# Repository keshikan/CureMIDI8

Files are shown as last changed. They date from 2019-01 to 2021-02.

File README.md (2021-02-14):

# USB-MIDI Interface (8IN/8OUT) for STM32 "CureMIDI8"

## Overview (概要)

This repository shows STM32F7 (ARM Cortex-M7) based  8IN/8OUT USB-MIDI Interface.
It is USB MIDI class-compliant, so you can add MIDI port without drivers(Windows, iOS, Android, etc...)

The USB-MIDI Class Driver is based on [mimuz-tuch](https://github.com/mimuz/mimuz-tuch) project (c) [D.F.Mac. @TripArts Music](https://github.com/tadfmac).

STM32F7を使用した、USB-MIDIインターフェースです。INを8系統、OUTを8系統実装しています。USB MIDI Classに対応するシステム(Windows, iOS, Android, etc.)に対し、ドライバレスでMIDI入出力ポートを追加できます。

USB MIDI Classドライバは、[D.F.Mac. @TripArts Music](https://github.com/tadfmac)氏作成の[ドライバ](https://github.com/mimuz/mimuz-tuch/tree/master/STM32)を元に、I/F部(usbd_midi_if.c/h)の改造を行っています。

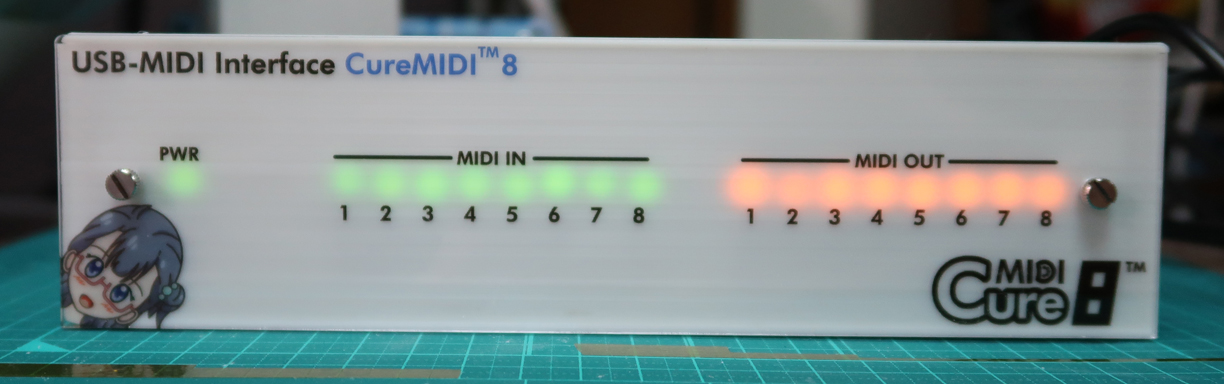
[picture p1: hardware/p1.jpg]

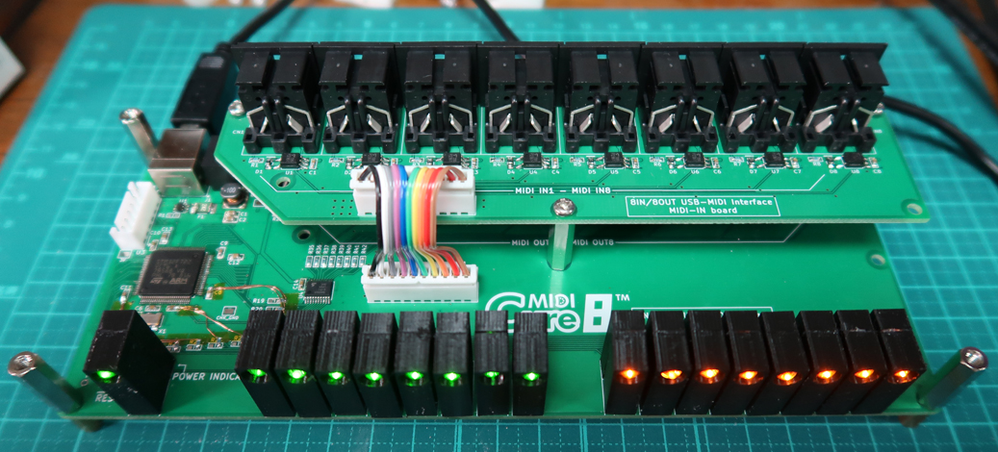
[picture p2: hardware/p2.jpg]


## Specifications (特徴)

* High-Speed MCU (STM32F722VCT)
* USB MIDI class-compliant
* MIDI port: 8IN/8OUT
* MIDI buffer size: 2kB * (8IN+8OUT) = 32kB

## Building Information (ビルド方法)

### Making hardware

See [Schematic](./hardware/schematic.pdf), [KiCad Source](./hardware/kicad_source).
CureMIDI8 consist of a mainboard and a MIDI-IN board.

回路図は[こちら](./hardware/schematic.pdf).
CureMIDI8は、メイン基板(Mainboard)と、拡張基板(MIDI-IN board)に分かれています。

### Building software

Install [STM32CubeIDE](https://www.st.com/ja/development-tools/stm32cubeide.html), import [Project files](./software/CubeIDE_project/). If you have successfully imported, you can build the project without error and the binary file will be created in /CubeIDE_project/Debug/.

[STM32CubeIDE](https://www.st.com/ja/development-tools/stm32cubeide.html)をインストールし、[プロジェクトファイル](./software/CubeIDE_project/)をインポートして下さい。インポートに成功していれば、STM32CubeIDE上でプロジェクトをビルドするだけで、/SW4STM32_project/Debug/フォルダにバイナリファイルが生成されるはずです。

## How to Porting (ポーティング方法)

### CubeIDE Project (recommended)

Refer to [here](software/README.md). (written in Japanese)

[こちら](software/README.md)を参照して下さい。

### SW4STM32 Project

(Older Information)
Load CureMIDI8.ioc on [STM32CubeMX (Ver.5.0.1)](https://www.st.com/ja/development-tools/stm32cubemx.html), change the pin assignment, and generate code.
After code generation, copy usb device driver as described below. You can use ./click_after_code_generation.bat (in Windows).

(以下は古い情報です)
CureMIDI8.iocを[STM32CubeMX (Ver.5.0.1)](https://www.st.com/ja/development-tools/stm32cubemx.html)で読みこみ、ポートを適宜修正し、コード生成をして下さい。コードを生成後、./template下のUSBドライバを、下記の通り上書きして下さい。上書きは、./click_after_code_generation.batを実行してもOKです。

* ./template/\*.c => ./Src/\*.c
* ./template/\*.h => ./Inc/\*.h

## File Location (ファイルの場所)

* [Binary file for STM32F722](./software/bin/)
* [STM32CubeIDE + STM32CubeMX(6.1.1) Project file](./software/CubeIDE_Project/)
* [SW4STM32 + STM32CubeMX(5.0.1) Project file](./software/SW4STM32_project/)
* [Schematic](./hardware/schematic.pdf)

## NOTICE (注意)

### VID/PID

Vendor ID(VID) and Product ID(PID) in <usbd_desc.c> should be unique pair for each USB devices.
Default VID 0x1209 and PID 0x0001 is experimental IDs from [http://pid.codes](http://pid.codes) .When distributing or selling, you must get your own IDs, and change to your own IDs in order to avoid conflicting to other USB devices.

USBのVendor ID(VID)とProduct ID(PID)は、<usbd_desc.c>内に記述します。
デフォルトのVID(0x1209)/PID(0x0001)ペアは、[http://pid.codes](http://pid.codes)で定められている実験用IDです。そのため、本機器を配布したり販売したりする場合には、別途固有のIDペアを取得し、書き換えてご使用いただく必要があります。

## References (参考情報)

### MIDI specification

* [The Complete MIDI 1.0 Detailed Specification](https://www.midi.org/specifications/item/the-midi-1-0-specification) ([MIDI Association](https://www.midi.org/))
* [MIDI1.0規格書](http://amei.or.jp/midistandardcommittee/MIDI1.0.pdf) ([AMEI](http://amei.or.jp/))
* [MIDIの学習](http://www1.plala.or.jp/yuuto/midi/index.html) ([Laboratory "U"](http://www1.plala.or.jp/yuuto/top.html))

### USB-MIDI technical information

* [Universal Serial Bus Device Class Definition for MIDI Devices](http://www.usb.org/developers/docs/devclass_docs/midi10.pdf)
* [USBおよびUSB MIDIについて調べる](http://picmidi.seesaa.net/article/150728556.html) ([PICでMIDI！](http://picmidi.seesaa.net/))

## Copyrights (著作権)

* USB MIDI Class Driver by [D.F.Mac. @TripArts Music](http://ta-music.strikingly.com/)
* STM32 CubeF7 by [STMicroelectronics](https://www.st.com/en/embedded-software/stm32cubef7.html)

## Author (著者)

(c) 2019 Keshikan ( [Website](http://www.keshikan.net/),  [Twitter](https://twitter.com/keshinomi_88pro) )

## License (ライセンス)

* USB MIDI Class Driver: [CC BY 4.0](https://creativecommons.org/licenses/by/4.0/)
* STM32 CubeF7: BSD-3-Clause based.
* Other Codes, Hardware, Schematic: [GPLv3](https://www.gnu.org/licenses/gpl-3.0.html)

See also [LICENSE.md](./LICENSE.md)

## Update History (更新履歴)

* (2021/02/14)
  * Added STM32CubeIDE(1.5.1) + CubeMX(6.1.1) Project.
* (2019/01/14)
  * Initial Release.

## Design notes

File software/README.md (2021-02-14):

# CureMIDI8 プロジェクトファイル (2021/2/14更新)

## フォルダ内容

* CubeIDE_project
  * [STM32CubeIDE](https://www.st.com/ja/development-tools/stm32cubeide.html)用のプロジェクトです。
* SW4STM32_project
  * [SW4STM32](http://www.openstm32.org/HomePage)用のプロジェクトです。古いので非推奨。

## CubeIDE_projectフォルダについて

最新の開発環境(2021/2/14現在)に対応させたプロジェクトファイル一式です。以下の環境でビルドと動作確認をしています。

* STM32CubeMX Version 6.1.1
* STM32CubeF7 V1.16.0
* STM32CubeIDE Version 1.5.1
* Windows10 20H2

## ポーティング手順

既存のCubeMX+CubeIDEのプロジェクトに対し、本プロジェクトのUSB-MIDIドライバを組み込むための手順を示します。今のところ、以下のMCU(括弧内はライブラリVer)で実績があります。

* STM32H750VB(STM32CubeH7 V1.8.0)
* STM32F722VC(STM32CubeF7 V1.16.0)
* STM32F407VG(STM32CubeF4 V1.25.2)

### CubeMXの設定

* USB_OTG_FSをDevice_Onlyに設定する。

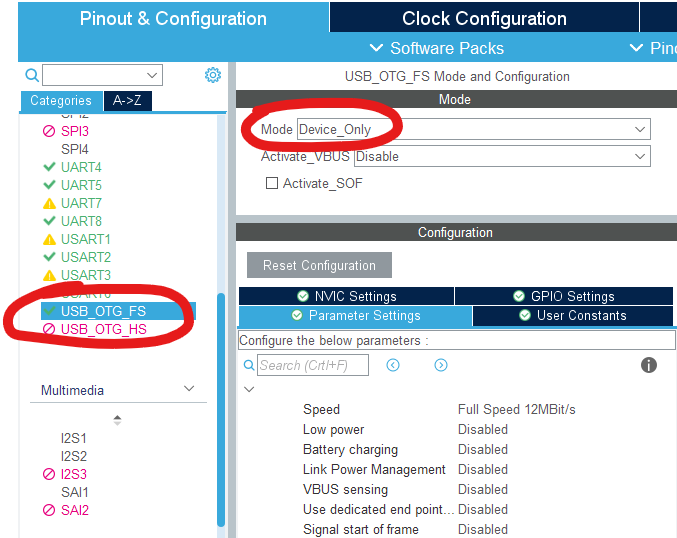
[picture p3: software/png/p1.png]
  * 

* USB_DEVICEで、Human Interface Device Class(HID)を選び、Device Descriptorを画像のように設定する。必要に応じて書き換える。(VID/PIDは実験用なので、他のIDに書き換えることを推奨)

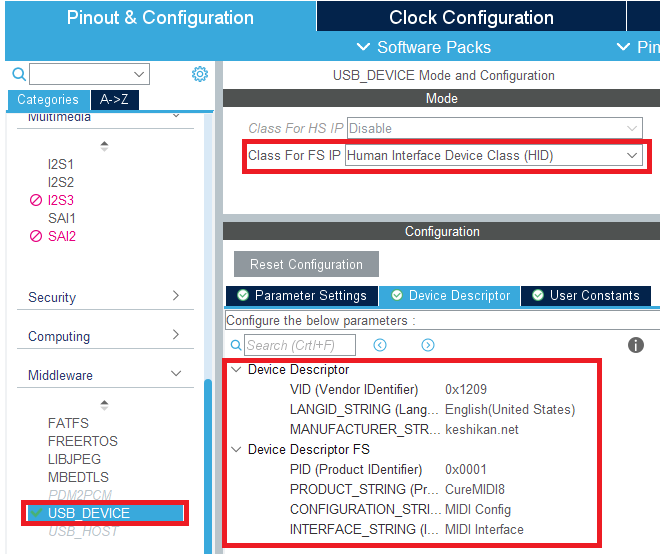
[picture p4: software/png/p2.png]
  * 

* Project ManagerタブのAdvanced Settingsを開き、MX_USB_DEVICE_Initの行の"Do Not Generate Function Call"チェックボックスをONにする。

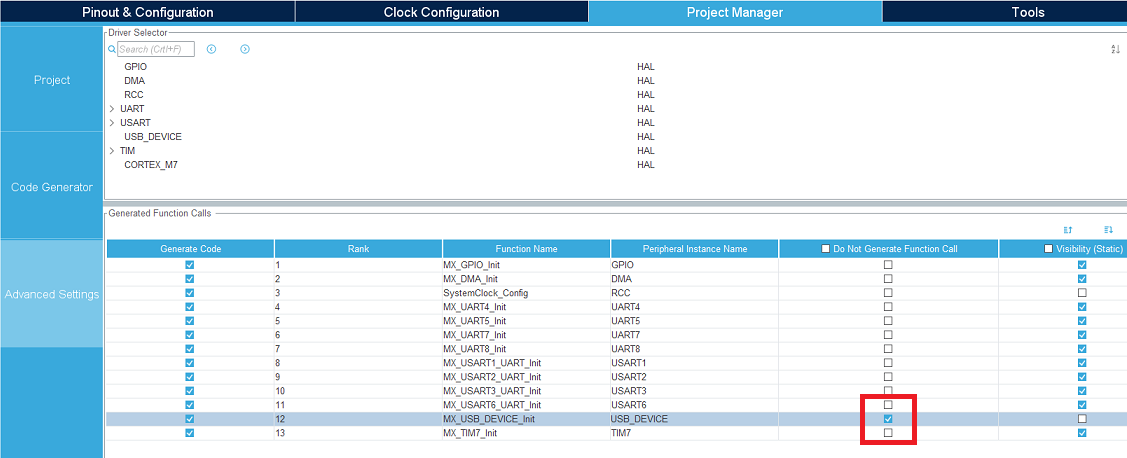
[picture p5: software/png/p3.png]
  * 

### ファイルのコピー

お使いのプロジェクトに、以下のファイルをコピーする。フォルダ構成も同一にしておく。

* Middlewares/USB-MIDI フォルダ一式
* USB_DEVICE/App/iflib フォルダ一式
* USB_DEVICE/Appのusbd_device.c/hを、本リポジトリのもので上書き

### CubeIDEの設定その他

* 以下でincludeされている「stmf7**.h」をMCUに合わせて書き直す。例：STM32F4にポーティングするなら、f7→f4にする。
  * /USB_DEVICE/App/usb_device.h
  * /USB_DEVICE/App/iflib/usbd_midi_if.h
  * /Middlewares/USBMIDI/usbd_midi.h
* プロジェクトのプロパティを開き、インクルードパスに以下を追加する。
  * ../Middlewares/USBMIDI
  * ../USB_DEVICE/App/iflib
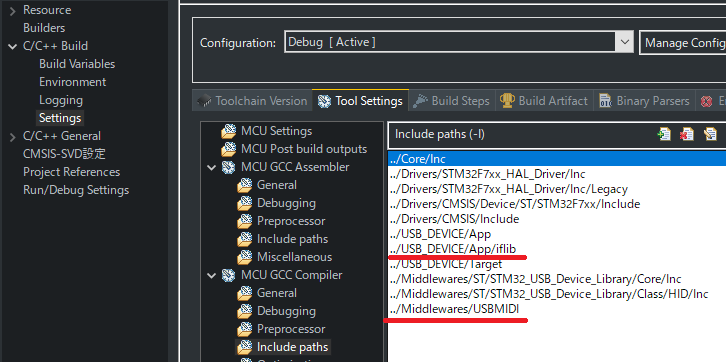
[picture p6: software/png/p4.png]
  * 

### ドライバの設定項目

その他、環境に合わせて以下の項目を設定する。

* MIDIのポート数設定：/Middlewares/USBMIDI/usbd_midi.h
  * MIDI_OUT_JACK_NUM・MIDI_IN_JACK_NUMが、それぞれMIDI OUT/INのポート数に対応している。ただし、この定義変更だけでは正常に動作しない(要改善)
  * 上記に加え、usbd_midi.c内のDevice Configuration Descriptorを正しく記述する必要がある。詳細は、[USB MIDI Devices 1.0(仕様書)](https://usb.org/sites/default/files/midi10.pdf)や、[こちらのページ](https://pcm1723.hateblo.jp/entry/20150106/1420519745)を参照

* MIDIバッファサイズの設定：/USB_DEVICE/App/iflib/usbd_midi_if.h
  * UM_MIDI_BUFFER_LENGTH で、1ポートあたりのMIDIバッファサイズを指定する。デフォルトは2048[byte]。2のべき乗に設定する。

### 使い方

* usbd_midi_if.h, usb_device.hをincludeする。
* MX_USB_MIDI_INIT()とmidiInit()を呼ぶことで、ドライバが初期化される。
* デバイス側がホスト側より受信したデータは、自動的に内部の受信用FIFOバッファにpushされる。このバッファからは、midiGetFromUsbRx(port, &dat)で1バイトずつ、順に取り出すことができる。portはポート番号(0から始まる)。datにデータが1byte分入る。データが取り出せない(バッファが空)の場合はFUNC_ERRORを返す。
* デバイス側がホスト側に対してデータを送信したいときは、midiSetFromJackRx(port, &dat)で、1バイトずつ内部の送信用FIFOバッファにpushすることができる。バッファの内容は、midiInProcess()を呼ぶタイミングでホストに送信される。

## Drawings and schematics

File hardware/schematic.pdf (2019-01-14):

19 A0

## From ST-LINK/V2

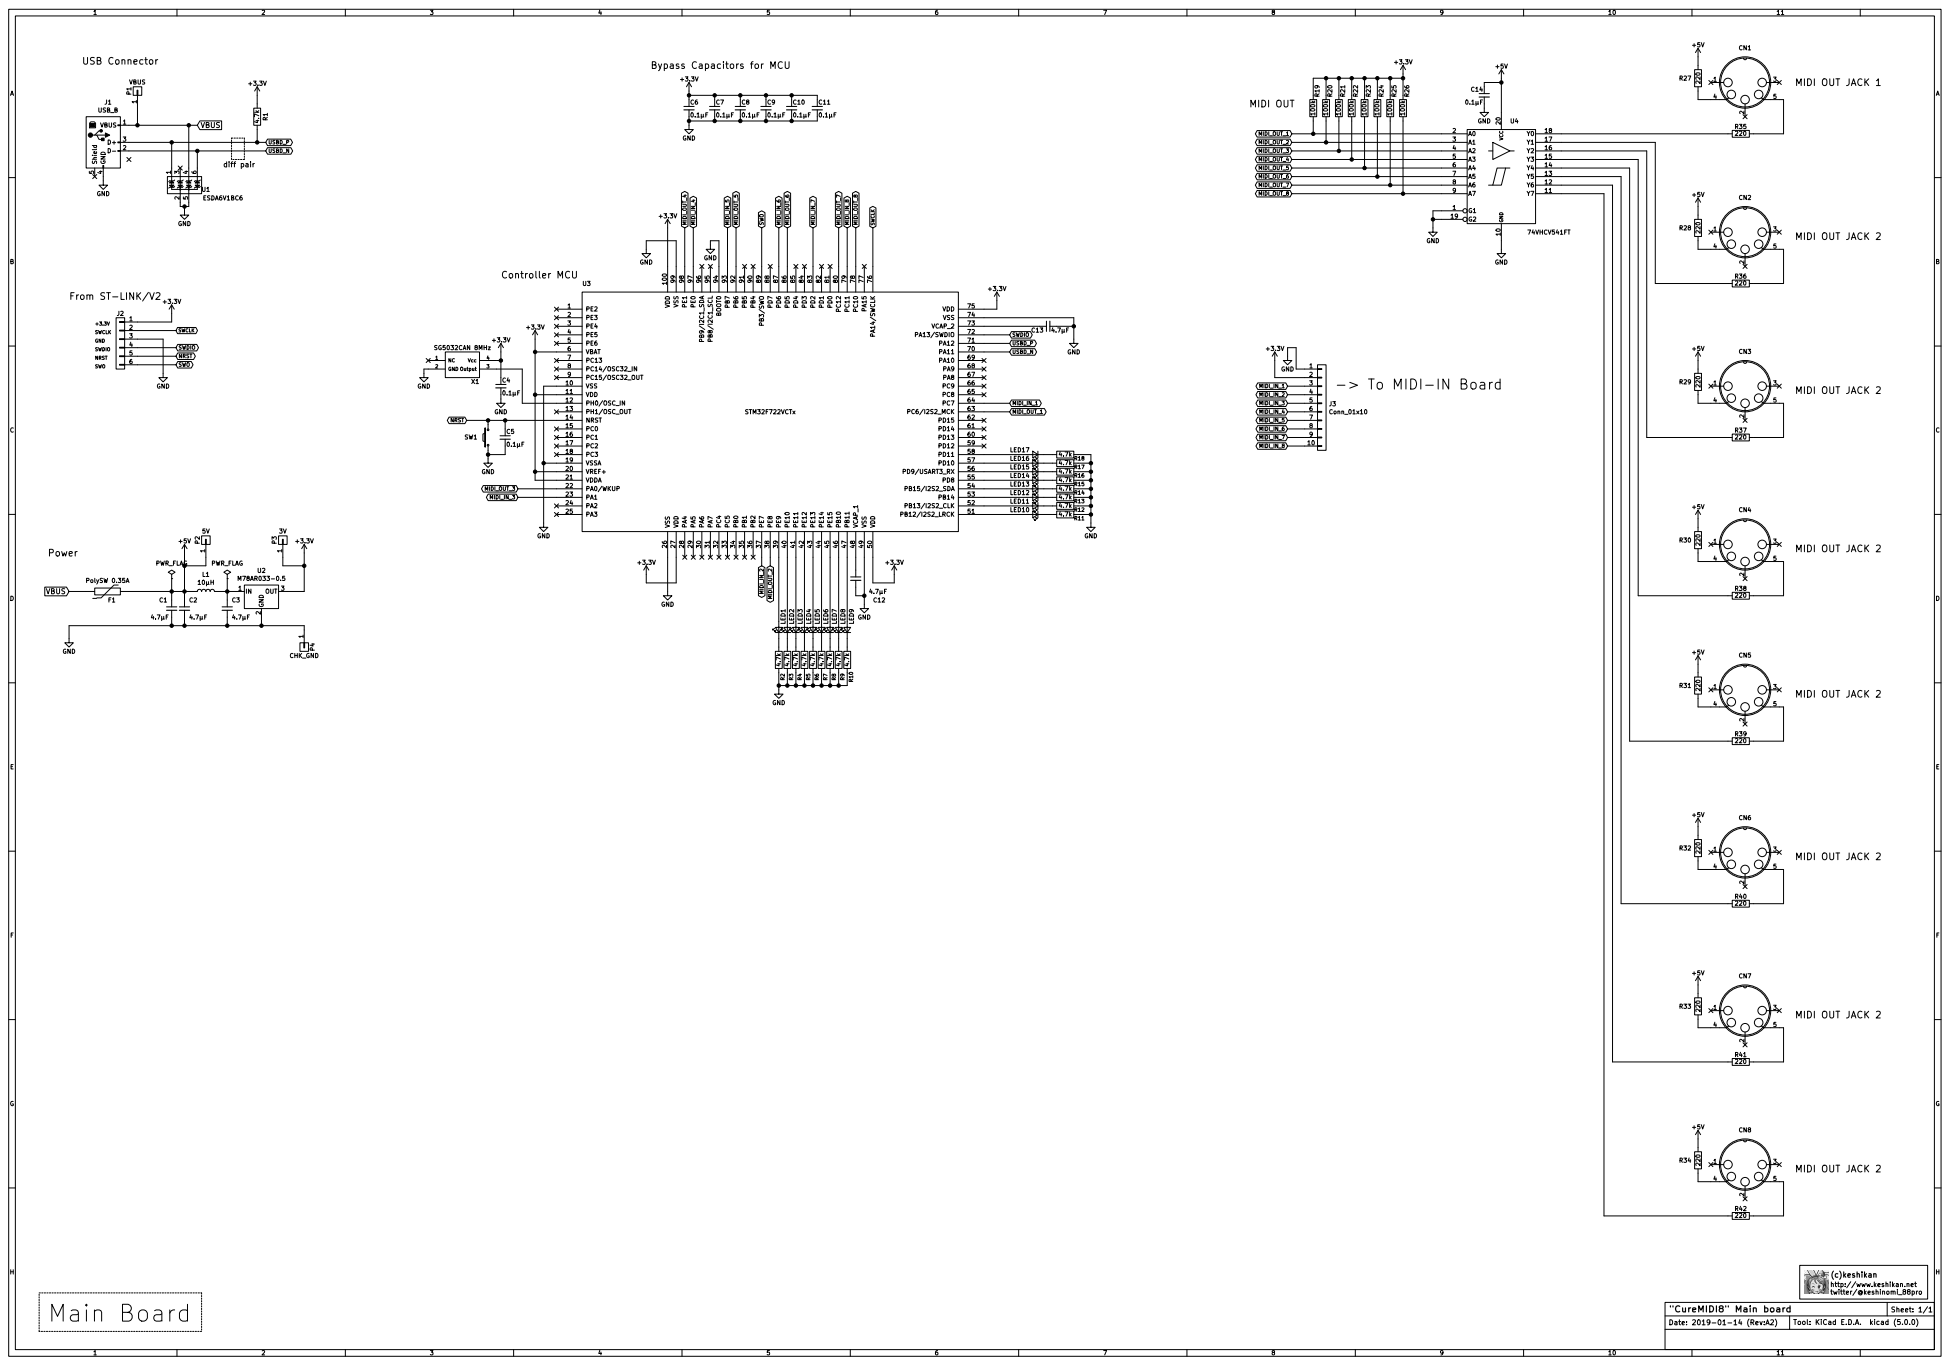
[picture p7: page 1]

Bypass Capacitors for MCU

R11 4.7k R¹⁰ ⁴.7k R⁹ ⁴.7k R⁸ ⁴.7k R⁷ ⁴.7k R⁶ ⁴.7k R⁵ ⁴.7k R⁴ ⁴.7k R³ ⁴.7k GND

(c)keshikan
http://www.keshikan.net

"CureMIDI8" MIDI-IN board | Sheet: 1/1 ¹ ² ³⁵ | 4 CN1 | R1 220 D1 | C1

## MIDI IN JACK 5

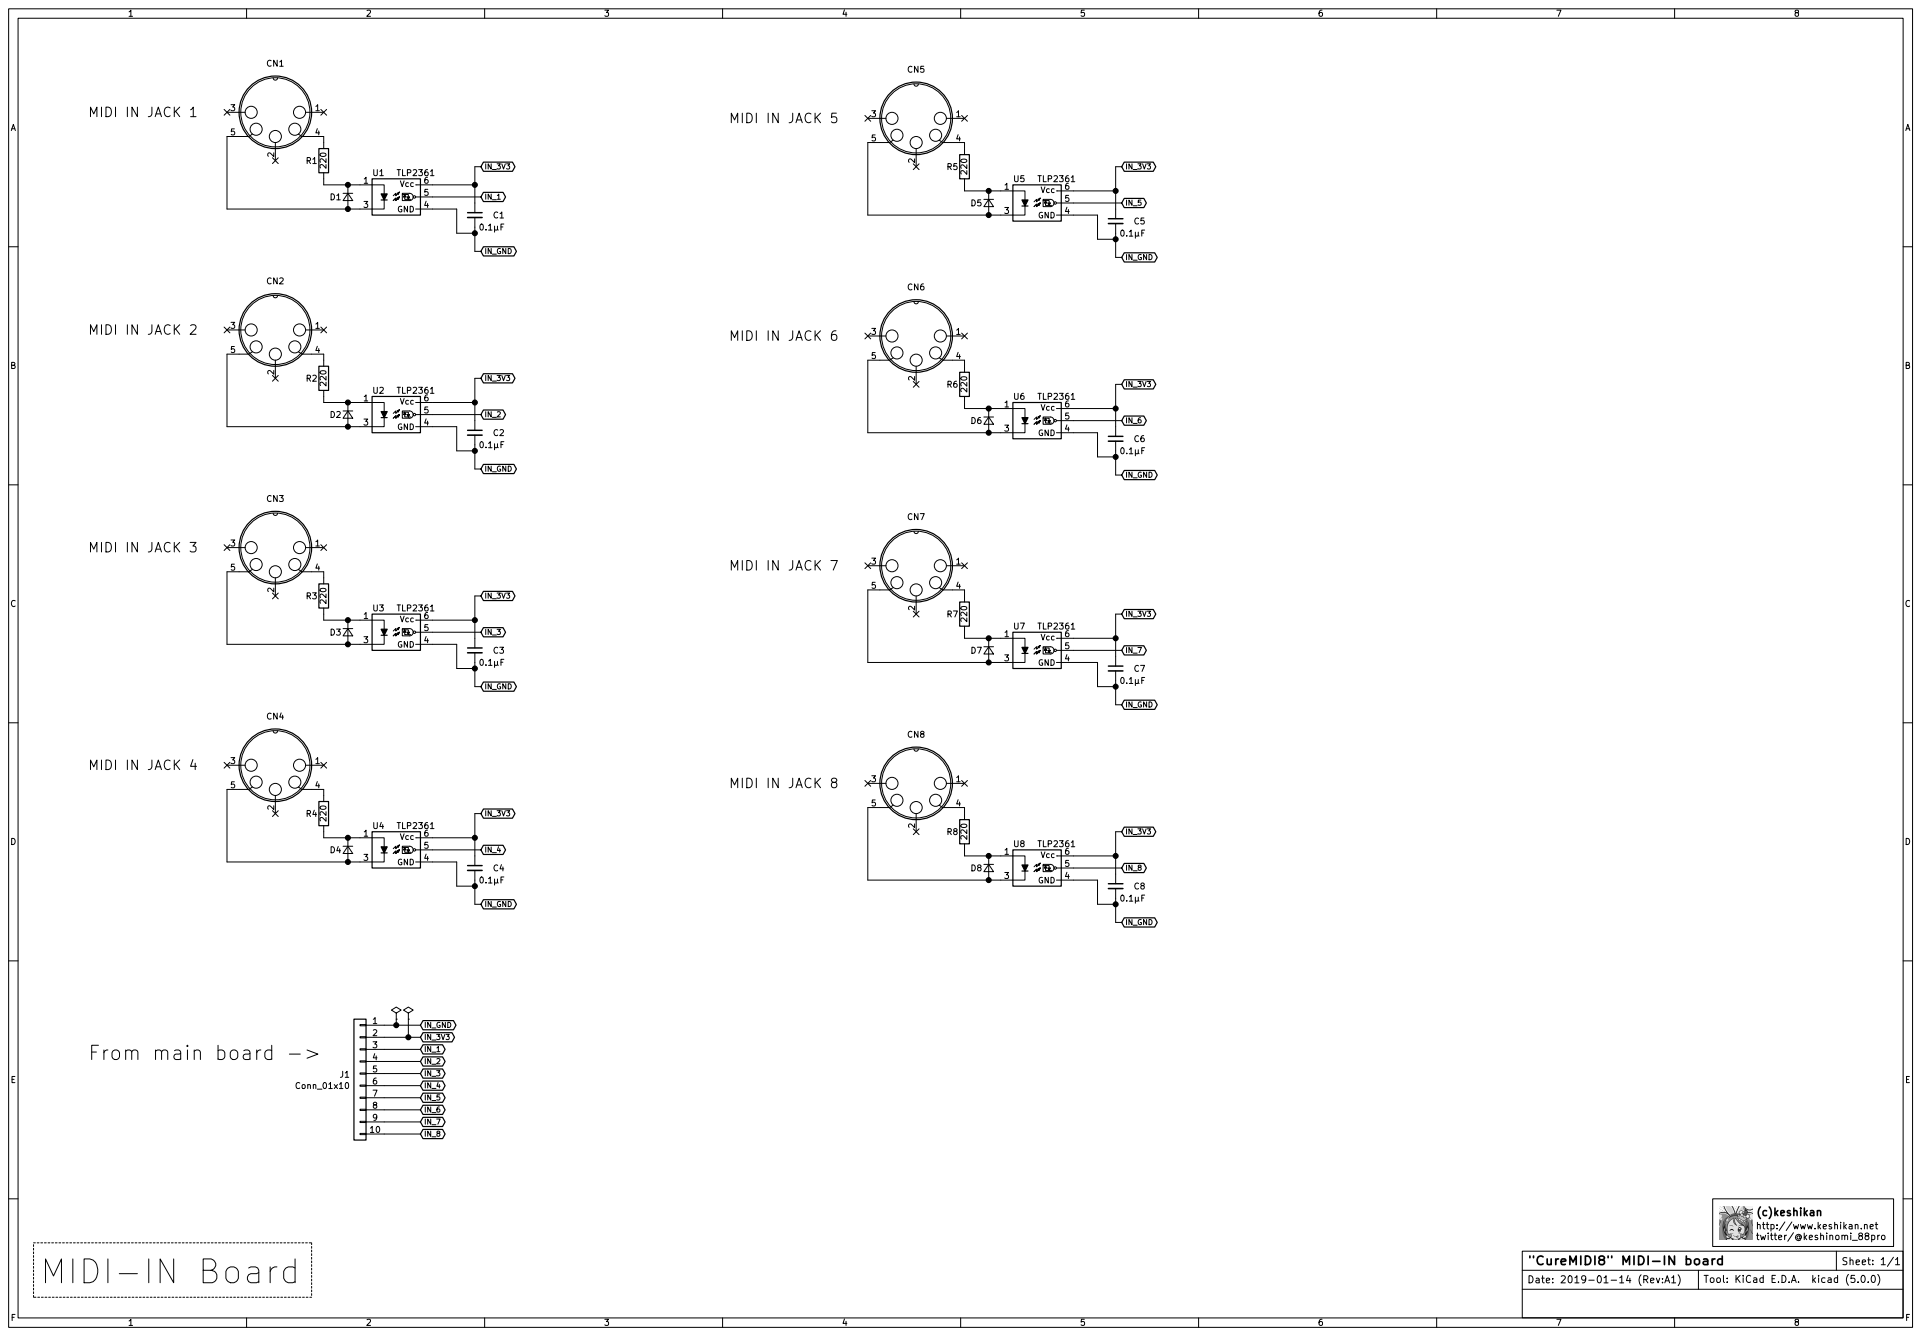
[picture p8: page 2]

(c)keshikan
http://www.keshikan.net

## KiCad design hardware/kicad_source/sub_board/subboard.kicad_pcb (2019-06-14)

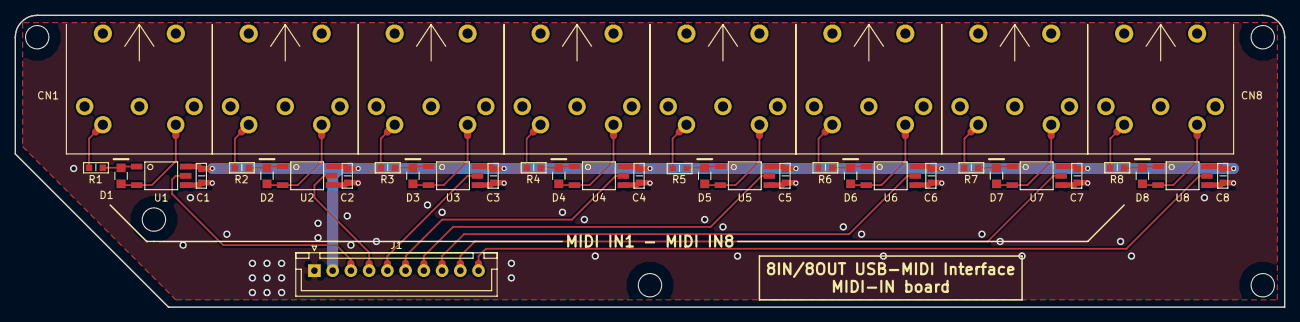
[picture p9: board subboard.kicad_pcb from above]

Board: 2 copper layers, 174.0 x 40.0 mm, 41 parts (0 on the bottom side), 34 nets.

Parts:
C1, C2, C3, C4, C5, C6, C7, C8: 0.1μF; SMD_0603(1608)
CN1, CN2, CN3, CN4, CN5, CN6, CN7, CN8: DIN_5; DIN_5P_MIDI
D1, D2, D3, D4, D5, D6, D7, D8: D_Small; SMD_0805(2012)_polar
J1: Conn_01x10; JST_XH_B10B-XH-A_10x2.50mm_Straight
R1, R2, R3, R4, R5, R6, R7, R8: 220; SMD_0603(1608)
U1, U2, U3, U4, U5, U6, U7, U8: TLP2361; 11-4L1S(TLP2361)

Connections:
IN_1: J1.3, U1.5
IN_2: J1.4, U2.5
IN_3: J1.5, U3.5
IN_3V3: C1.1, C2.1, C3.1, C4.1, C5.1, C6.1, C7.1, C8.1, J1.2, U1.6, U2.6, U3.6, U4.6, U5.6, U6.6, U7.6, U8.6
IN_4: J1.6, U4.5
IN_5: J1.7, U5.5
IN_6: J1.8, U6.5
IN_7: J1.9, U7.5
IN_8: J1.10, U8.5
IN_GND: C1.2, C2.2, C3.2, C4.2, C5.2, C6.2, C7.2, C8.2, J1.1, U1.4, U2.4, U3.4, U4.4, U5.4, U6.4, U7.4, U8.4
unnamed: CN1.4, R1.1
unnamed: CN1.5, D1.2, U1.3
unnamed: CN2.4, R2.1
unnamed: CN2.5, D2.2, U2.3
unnamed: CN3.4, R3.1
unnamed: CN3.5, D3.2, U3.3
unnamed: CN4.4, R4.1
unnamed: CN4.5, D4.2, U4.3
unnamed: CN5.4, R5.1
unnamed: CN5.5, D5.2, U5.3
unnamed: CN6.4, R6.1
unnamed: CN6.5, D6.2, U6.3
unnamed: CN7.4, R7.1
unnamed: CN7.5, D7.2, U7.3
unnamed: CN8.4, R8.1
unnamed: CN8.5, D8.2, U8.3
unnamed: D1.1, R1.2, U1.1
unnamed: D2.1, R2.2, U2.1
unnamed: D3.1, R3.2, U3.1
unnamed: D4.1, R4.2, U4.1
unnamed: D5.1, R5.2, U5.1
unnamed: D6.1, R6.2, U6.1
unnamed: D7.1, R7.2, U7.1
unnamed: D8.1, R8.2, U8.1

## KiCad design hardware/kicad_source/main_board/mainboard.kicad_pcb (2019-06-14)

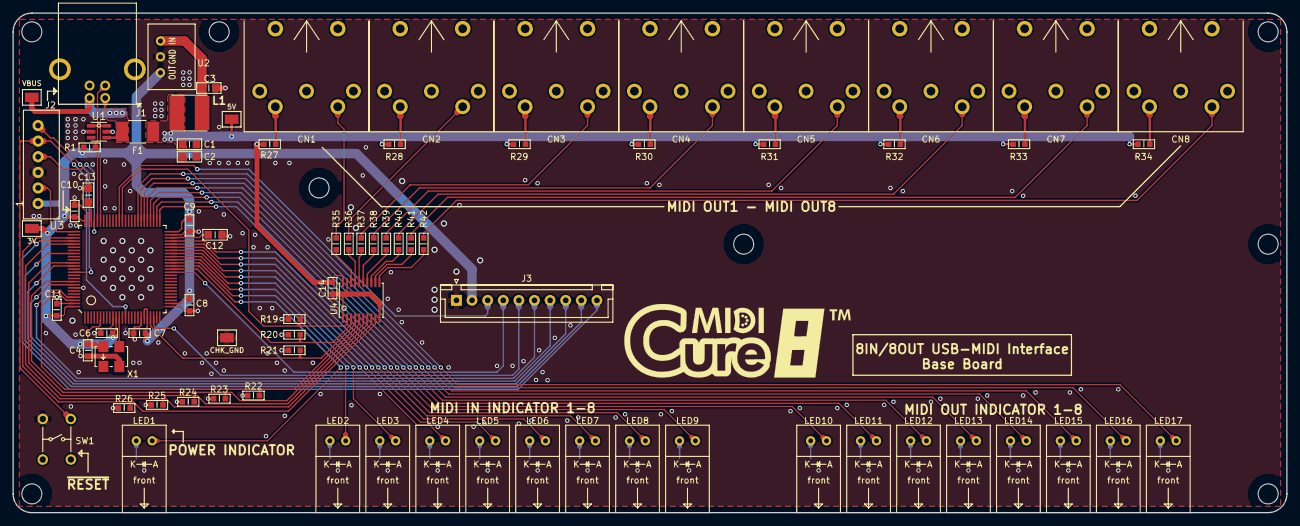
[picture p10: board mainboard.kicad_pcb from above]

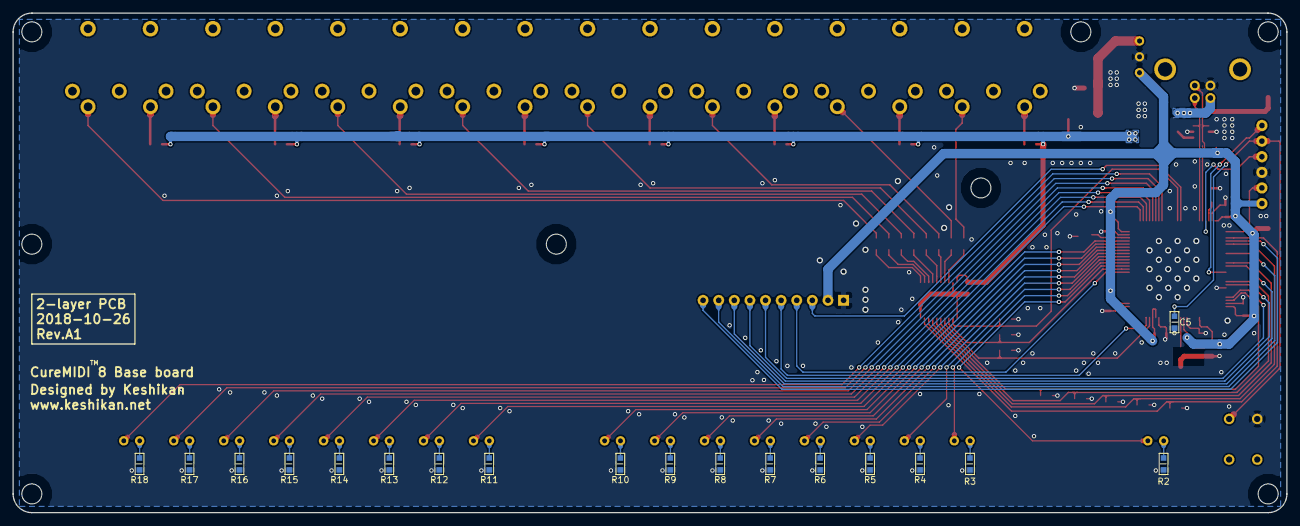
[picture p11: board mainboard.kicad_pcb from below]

Board: 2 copper layers, 204.0 x 80.0 mm, 96 parts (18 on the bottom side), 88 nets.

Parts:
C1, C2, C3, C12, C13: 4.7μF; SMD_0805(2012)
C4, C5, C6, C7, C8, C9, C10, C11, C14: 0.1μF; SMD_0603(1608)
CN1, CN2, CN3, CN4, CN5, CN6, CN7, CN8: DIN_5; DIN_5P_MIDI
F1: PolySW 0.35A; miniSMDC030F
J1: USB_B; USB_B_F
J2: CONN_01X06; XH-6P-TOP
J3: Conn_01x10; JST_XH_B10B-XH-A_10x2.50mm_Straight
L1: 10μH; Wurth_Elektronik_74477410
LED1, LED2, LED3, LED4, LED5, LED6, LED7, LED8, LED9, LED10, LED11, LED12, LED13, LED14, LED15, LED16, LED17: LED_Small; LEDSpacer_1low
P1: VBUS; CHK_Terminal_SMD
P2: 5V; CHK_Terminal_SMD
P3: 3V; CHK_Terminal_SMD
P4: CHK_GND; CHK_Terminal_SMD
R1, R2, R3, R4, R5, R6, R7, R8, R9, R10, R11, R12, R13, R14, R15, R16, R17, R18: 4.7k; SMD_0603(1608)
R19, R20, R21, R22, R23, R24, R25, R26: 100k; SMD_0603(1608)
R27, R28, R29, R30, R31, R32, R33, R34, R35, R36, R37, R38, R39, R40, R41, R42: 220; SMD_0603(1608)
SW1: SW_PUSH_SMALL_H; Tactile_Switches_2by2
U1: ESDA6V1BC6; SOT23-6L
U2: M78AR033-0.5
U3: STM32F722VCTx; LQFP100_14x14_STM32
U4: 74VHCV541FT; TSSOP20B
X1: SG5032CAN 8MHz; SG5032

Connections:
+3V3: C4.1, C6.1, C7.1, C8.1, C9.1, C10.1, C11.1, J2.1, J3.2, P3.1, R1.2, U2.3, U3.6, U3.11, U3.20, U3.21, U3.27, U3.50, U3.75, U3.100, X1.4
+5V: C1.1, C2.1, C14.1, F1.1, L1.1, P2.1, R27.1, R28.1, R29.1, R30.1, R31.1, R32.1, R33.1, R34.1, U4.20
GND: C1.2, C2.2, C3.2, C4.2, C5.2, C6.2, C7.2, C8.2, C9.2, C10.2, C11.2, C12.2, C13.2, C14.2, J1.4, J2.3, J3.1, P4.1, R2.1, R3.1, R4.1, R5.1, R6.1, R7.1, R8.1, R9.1, R10.1, R11.1, R12.1, R13.1, R14.1, R15.1, R16.1, R17.1, R18.1, R19.1, R20.1, R21.1, R22.1, R23.1, R24.1, R25.1, R26.1, SW1.1, U1.2, U1.5, U2.2, U3.10, U3.19, U3.26, U3.49, U3.74, U3.94, U3.99, U4.1, U4.10, U4.19, X1.2
MIDI_IN_1: J3.3, U3.64
MIDI_IN_2: J3.4, U3.37
MIDI_IN_3: J3.5, U3.23
MIDI_IN_4: J3.6, U3.97
MIDI_IN_5: J3.7, U3.93
MIDI_IN_6: J3.8, U3.87
MIDI_IN_7: J3.9, U3.83
MIDI_IN_8: J3.10, U3.79
MIDI_OUT_1: R19.2, U3.63, U4.2
MIDI_OUT_2: R20.2, U3.38, U4.3
MIDI_OUT_3: R21.2, U3.22, U4.4
MIDI_OUT_4: R22.2, U3.98, U4.5
MIDI_OUT_5: R23.2, U3.92, U4.6
MIDI_OUT_6: R24.2, U3.86, U4.7
MIDI_OUT_7: R25.2, U3.80, U4.8
MIDI_OUT_8: R26.2, U3.78, U4.9
NRST: C5.1, J2.5, SW1.2, U3.14
unnamed: C3.1, L1.2, U2.1
unnamed: C12.1, U3.48
unnamed: C13.1, U3.73
unnamed: CN1.4, R27.2
unnamed: CN1.5, R35.2
unnamed: CN2.4, R28.2
unnamed: CN2.5, R36.2
unnamed: CN3.4, R29.2
unnamed: CN3.5, R37.2
unnamed: CN4.4, R30.2
unnamed: CN4.5, R38.2
unnamed: CN5.4, R31.2
unnamed: CN5.5, R39.2
unnamed: CN6.4, R32.2
unnamed: CN6.5, R40.2
unnamed: CN7.4, R33.2
unnamed: CN7.5, R41.2
unnamed: CN8.4, R34.2
unnamed: CN8.5, R42.2
unnamed: LED1.1, R2.2
unnamed: LED1.2, U3.39
unnamed: LED2.1, R3.2
unnamed: LED2.2, U3.40
unnamed: LED3.1, R4.2
unnamed: LED3.2, U3.41
unnamed: LED4.1, R5.2
unnamed: LED4.2, U3.42
unnamed: LED5.1, R6.2
unnamed: LED5.2, U3.43
unnamed: LED6.1, R7.2
unnamed: LED6.2, U3.44
unnamed: LED7.1, R8.2
unnamed: LED7.2, U3.45
unnamed: LED8.1, R9.2
unnamed: LED8.2, U3.46
unnamed: LED9.1, R10.2
unnamed: LED9.2, U3.47
unnamed: LED10.1, R11.2
unnamed: LED10.2, U3.51
unnamed: LED11.1, R12.2
unnamed: LED11.2, U3.52
unnamed: LED12.1, R13.2
unnamed: LED12.2, U3.53
unnamed: LED13.1, R14.2
unnamed: LED13.2, U3.54
unnamed: LED14.1, R15.2
unnamed: LED14.2, U3.55
unnamed: LED15.1, R16.2
unnamed: LED15.2, U3.56
unnamed: LED16.1, R17.2
unnamed: LED16.2, U3.57
unnamed: LED17.1, R18.2
unnamed: LED17.2, U3.58
unnamed: R35.1, U4.18
unnamed: R36.1, U4.17
unnamed: R37.1, U4.16
unnamed: R38.1, U4.15
unnamed: R39.1, U4.14
unnamed: R40.1, U4.13
unnamed: R41.1, U4.12
unnamed: R42.1, U4.11
unnamed: U3.12, X1.3
SWCLK: J2.2, U3.76
SWDIO: J2.4, U3.72
SWO: J2.6, U3.89
USBD_N: J1.2, U1.6, U3.70
USBD_P: J1.3, R1.1, U1.1, U3.71
VBUS: F1.2, J1.1, P1.1, U1.4

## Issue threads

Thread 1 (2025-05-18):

STM32F4への移植でサポートいただけますか？

tunaingot, 2025-05-18:
CureMIDI8のプロジェクトを拝見しました。
とても興味深く、自分でもMIDIマージ機能などを追加したものを作ってみようと思います。

`STM32F407Discovery`を使って試作しようとしています。
README.mdやポーティングの解説を見ながら、新規プロジェクトをCubeIDEで作り、コードの修正、ドライバ類ファイルのコピーをしました。

ビルドすると、添付のようなエラーが出るのですが、この理由はお分かりになりますか？
ちなみに、提供されているCubeMIDI8_cubeide(STM21F7のプロジェクト)ではエラーが出ません。

サポートいただけると幸いです。

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

keshikan, 2025-05-19:
以下のファイル中の`pUserData`を全て`pUserData[0]`に変更すればどうでしょう？

```
/Middlewares/USBMIDI/usbd_midi.c
/Middlewares/ST/STM32_USB_Device_Library/Core/Src/usbd_core.c
```

tunaingot, 2025-05-21:
コメントありがとうございます。

そうか、そっちの書き方を変えればいいんですね。
無事コンパイル通りました。

回路図も参考にさせていただいています。
どうもありがとうございました。

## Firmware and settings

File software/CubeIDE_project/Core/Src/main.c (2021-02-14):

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
/* Includes ------------------------------------------------------------------*/
#include "main.h"

/* USER CODE BEGIN Includes */
#include "usb_device.h"
#include "usbd_midi_if.h"
#include "device_conf.h"
#include "led_blink.h"
/* USER CODE END Includes */


TIM_HandleTypeDef htim7;

UART_HandleTypeDef huart4;
UART_HandleTypeDef huart5;
UART_HandleTypeDef huart7;
UART_HandleTypeDef huart8;
UART_HandleTypeDef huart1;
UART_HandleTypeDef huart2;
UART_HandleTypeDef huart3;
UART_HandleTypeDef huart6;
DMA_HandleTypeDef hdma_uart4_rx;
DMA_HandleTypeDef hdma_uart5_rx;
DMA_HandleTypeDef hdma_uart7_rx;
DMA_HandleTypeDef hdma_uart8_rx;
DMA_HandleTypeDef hdma_usart1_rx;
DMA_HandleTypeDef hdma_usart2_rx;
DMA_HandleTypeDef hdma_usart3_rx;
DMA_HandleTypeDef hdma_usart6_rx;

/* USER CODE BEGIN PV */
volatile bool isUartReady[MIDI_OUT_JACK_NUM];

//device porting for MIDI IN/OUT Jack
UART_HandleTypeDef* uart_handler[]=
{
		&MIDI_UART_HANDLER_1, &MIDI_UART_HANDLER_2, &MIDI_UART_HANDLER_3, &MIDI_UART_HANDLER_4,
		&MIDI_UART_HANDLER_5, &MIDI_UART_HANDLER_6, &MIDI_UART_HANDLER_7, &MIDI_UART_HANDLER_8
};

USART_TypeDef* uart_instance[]=
{
		UART_INSTANCE_PORT1, UART_INSTANCE_PORT2, UART_INSTANCE_PORT3, UART_INSTANCE_PORT4,
		UART_INSTANCE_PORT5, UART_INSTANCE_PORT6, UART_INSTANCE_PORT7, UART_INSTANCE_PORT8
};

uint8_t uart_tx_dat;

uint8_t uart_rx_dat[MIDI_IN_JACK_NUM];
/* USER CODE END PV */

void SystemClock_Config(void);
static void MX_GPIO_Init(void);
static void MX_DMA_Init(void);
static void MX_UART4_Init(void);
static void MX_UART5_Init(void);
static void MX_UART7_Init(void);
static void MX_UART8_Init(void);
static void MX_USART1_UART_Init(void);
static void MX_USART2_UART_Init(void);
static void MX_USART3_UART_Init(void);
static void MX_USART6_UART_Init(void);
static void MX_TIM7_Init(void);
/* USER CODE BEGIN 0 */

void initMisc()
{
	for(uint32_t i=0; i<MIDI_OUT_JACK_NUM; i++){
		isUartReady[i] = true;
	}
}

void HAL_TIM_PeriodElapsedCallback(TIM_HandleTypeDef *htim)
{

	if(htim->Instance == TIM7)
	{
		ledIncrementState();
	}

}

void HAL_UART_RxCpltCallback(UART_HandleTypeDef *huart)
{

	for(uint32_t i=0; i<MIDI_IN_JACK_NUM; i++){
		if(huart->Instance == uart_instance[i]){
			ledActivate(i);
			midiSetFromJackRx(i, &uart_rx_dat[i]);
			HAL_UART_Receive_DMA(uart_handler[i], &uart_rx_dat[i],1);
			break;
		}
	}
}

void HAL_UART_TxCpltCallback(UART_HandleTypeDef *huart)
{
	for(uint32_t i=0; i<MIDI_OUT_JACK_NUM; i++){
		if(huart->Instance == uart_instance[i]){
			ledActivate(MIDI_IN_JACK_NUM+i);
			isUartReady[i] = true;
			break;
		}
	}
}

//call after
void sendUart(uint8_t ch, uint8_t* dat)
{
	isUartReady[ch] = false;
	  __disable_irq();
	HAL_UART_Transmit_IT(uart_handler[ch], dat,1);
	  __enable_irq();
}
/* USER CODE END 0 */

/**
  * @brief  The application entry point.
  * @retval int
  */
int main(void)
{
  /* Enable I-Cache---------------------------------------------------------*/
  SCB_EnableICache();

  /* Enable D-Cache---------------------------------------------------------*/
  SCB_EnableDCache();

  /* MCU Configuration--------------------------------------------------------*/

  /* Reset of all peripherals, Initializes the Flash interface and the Systick. */
  HAL_Init();

  /* Configure the system clock */
  SystemClock_Config();

  /* Initialize all configured peripherals */
  MX_GPIO_Init();
  MX_DMA_Init();
  MX_UART4_Init();
  MX_UART5_Init();
  MX_UART7_Init();
  MX_UART8_Init();
  MX_USART1_UART_Init();
  MX_USART2_UART_Init();
  MX_USART3_UART_Init();
  MX_USART6_UART_Init();
  MX_TIM7_Init();
  /* USER CODE BEGIN 2 */

  //USB-MIDI Driver Init
  MX_USB_MIDI_INIT();

  if(FUNC_ERROR == midiInit() ){
	  while(1){
		  HAL_GPIO_WritePin(LED_POW_GPIO, LED_POW_PIN, SET);
		  HAL_Delay(500);
		  HAL_GPIO_WritePin(LED_POW_GPIO, LED_POW_PIN, RESET);
		  HAL_Delay(500);
	  }
  }

  //Init misc
  ledInit();
  initMisc();

  //Wait usb configuration.
  while(1){
	  if(USBD_STATE_CONFIGURED == hUsbDeviceFS.dev_state){
		  HAL_GPIO_WritePin(LED_POW_GPIO, LED_POW_PIN, SET);
		  break;
	  }else{
		  HAL_GPIO_WritePin(LED_POW_GPIO, LED_POW_PIN, RESET);
	  }
  }

  //start led-blinking timer
  HAL_TIM_Base_Start_IT(&htim7);

  //Start MIDI Receive from IN Jack
  for(uint32_t i=0; i<MIDI_IN_JACK_NUM; i++){
	  HAL_UART_Receive_DMA(uart_handler[i], &uart_rx_dat[i],1);
  }



  /* USER CODE END 2 */

  /* Infinite loop */
  /* USER CODE BEGIN WHILE */
  while (1)
  {
  /* USER CODE END WHILE */

  /* USER CODE BEGIN 3 */
	  //Wait USB configuration when USB connection error has occurred.
	  if(USBD_STATE_CONFIGURED != hUsbDeviceFS.dev_state){
		  while(1){
			  HAL_GPIO_WritePin(LED_POW_GPIO, LED_POW_PIN, SET);
			  HAL_Delay(200);
			  HAL_GPIO_WritePin(LED_POW_GPIO, LED_POW_PIN, RESET);
			  HAL_Delay(200);

			  if(USBD_STATE_CONFIGURED == hUsbDeviceFS.dev_state){
				  HAL_GPIO_WritePin(LED_POW_GPIO, LED_POW_PIN, SET);
				  break;
			  }
		  }
	  }

	  //MIDI-OUT: [USB-MIDI IN] to [MIDI JACK OUT]
	  for(uint32_t cable_num=0; cable_num<MIDI_OUT_JACK_NUM; cable_num++){
		  if( FUNC_SUCCESS == midiGetFromUsbRx(cable_num, &uart_tx_dat) ){
			  while(!isUartReady[cable_num]);
			  sendUart(cable_num, &uart_tx_dat);
		  }
	  }

	  //MIDI-IN: [MIDI JACK IN] to [USB-MIDI OUT]
	  midiInProcess();
	  ledMain();

  }
  /* USER CODE END 3 */
}

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


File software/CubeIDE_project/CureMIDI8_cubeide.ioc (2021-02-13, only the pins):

Mcu.UserName=STM32F722VCTx
PA0-WKUP.Signal=UART4_TX
PA1.Signal=UART4_RX
PA11.Signal=USB_OTG_FS_DM
PA12.Signal=USB_OTG_FS_DP
PA13.Signal=SYS_JTMS-SWDIO
PA14.Signal=SYS_JTCK-SWCLK
PB10.Signal=GPIO_Output
PB11.Signal=GPIO_Output
PB12.Signal=GPIO_Output
PB13.Signal=GPIO_Output
PB14.Signal=GPIO_Output
PB15.Signal=GPIO_Output
PB3.Signal=SYS_JTDO-SWO
PB6.Signal=USART1_TX
PB7.Signal=USART1_RX
PC10.Signal=USART3_TX
PC11.Signal=USART3_RX
PC12.Signal=UART5_TX
PC6.Signal=USART6_TX
PC7.Signal=USART6_RX
PD10.Signal=GPIO_Output
PD11.Signal=GPIO_Output
PD2.Signal=UART5_RX
PD5.Signal=USART2_TX
PD6.Signal=USART2_RX
PD8.Signal=GPIO_Output
PD9.Signal=GPIO_Output
PE0.Signal=UART8_RX
PE1.Signal=UART8_TX
PE10.Signal=GPIO_Output
PE11.Signal=GPIO_Output
PE12.Signal=GPIO_Output
PE13.Signal=GPIO_Output
PE14.Signal=GPIO_Output
PE15.Signal=GPIO_Output
PE7.Signal=UART7_RX
PE8.Signal=UART7_TX
PE9.Signal=GPIO_Output
PH0-OSC_IN.Signal=RCC_OSC_IN
PH1-OSC_OUT.Signal=RCC_OSC_OUT

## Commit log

2019-01-14 Modified circuit: R19-26(Main board) must be pulled-up.
2019-06-14 Added KiCad source files.
    [mainboard.kicad_pcb, mainboard.sch, subboard.kicad_pcb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]
2021-02-14 Modified readme: works with STM32H750VB

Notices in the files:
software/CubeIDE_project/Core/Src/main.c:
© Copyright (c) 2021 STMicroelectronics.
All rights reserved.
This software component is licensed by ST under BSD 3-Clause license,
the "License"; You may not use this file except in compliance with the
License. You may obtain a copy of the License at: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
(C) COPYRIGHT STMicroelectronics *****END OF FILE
